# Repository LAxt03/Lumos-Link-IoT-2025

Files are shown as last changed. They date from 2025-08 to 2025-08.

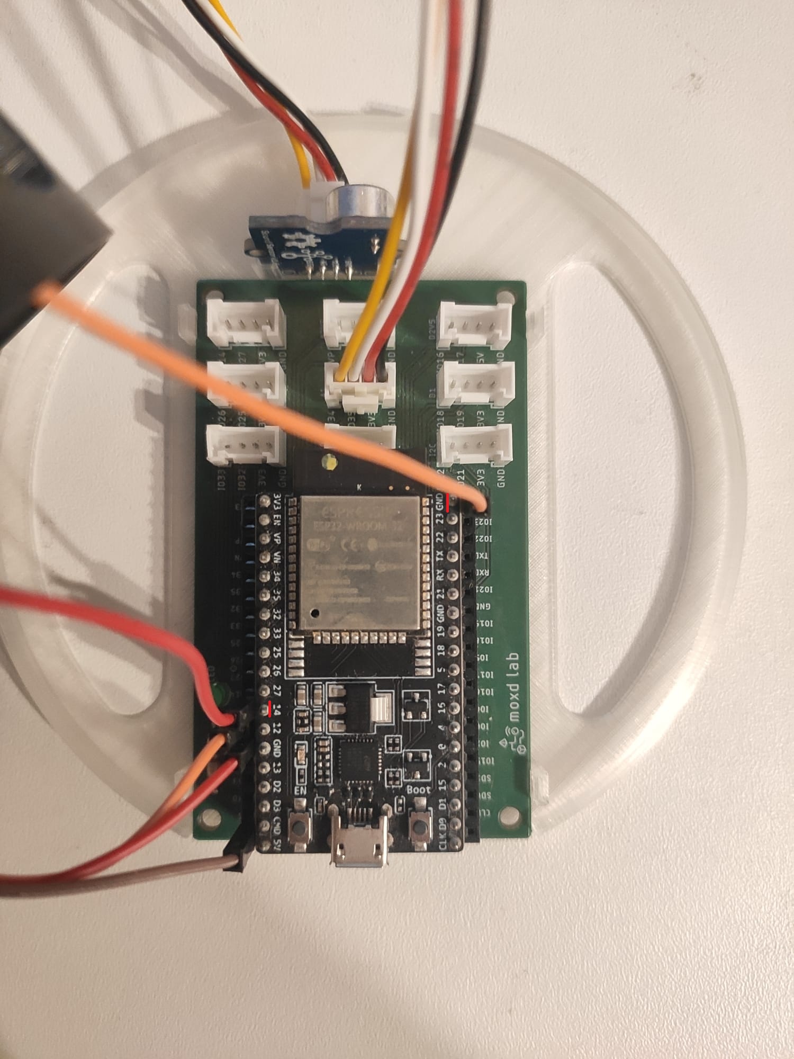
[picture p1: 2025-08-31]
DIY - Bilder/Schritt 11 -- Äußerer Taster an ESP32 anschließen.jpeg

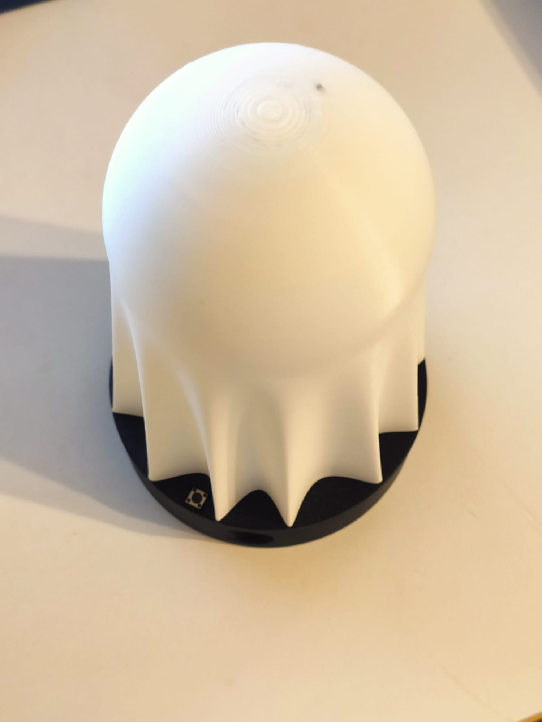
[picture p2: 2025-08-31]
DIY - Bilder/Schritt 17 -- Lumos-Geist über den Stabilitätsring platzieren.jpeg

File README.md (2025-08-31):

# Lumos-Link-IoT-2025
# DIY-Anleitung: Lumos-Lampe

Diese Anleitung beschreibt Schritt für Schritt, wie du deine Lumos-Lampe mit ESP32 und Sensoren aufbaust.
Zu allen Schritten der Aufbauanleitung sind Bilder in dem Ordner "DIY - Bilder" hinterlegt.

---

## 🔧 Benötigte Teile

- **1x ESP32**
- **1x LED-Ring**
- **1x Lichtsensor**
- **1x Sound-Sensor**
- **2x Taster** (jeweils mit 2 Kabeln angeschlossen)
- **1x 3-poliges Kabel**
- **3x Jumperkabel**
- **1x Plastikbase** (schwarz oder weiß)
- **1x transparente Plastikplatte**
- **1x LED-Ring-Kappe**
- **1x Lumos-Geist**
- **1x Stabilitätsring**

---

## 📖 Erklärung der Teile

- **ESP32**  
  Zentrale Steuereinheit, übernimmt die gesamte Logik, WLAN-Verbindung und Kommunikation über MQTT.  

- **LED-Ring**  
  Dient als visuelles Ausgabeelement und zeigt unterschiedliche Lichtmuster und Farben abhängig vom Zustand des Systems.  

- **Lichtsensor**  
  Misst die Umgebungshelligkeit, damit die Lampe nicht zu hell leuchtet und sich an die Lichtverhältnisse anpasst.  

- **Sound-Sensor**  
  Erkennt Geräusche in der Umgebung und dient als Auslöser für die Signale, die an andere Lumos-Lampen gesendet werden.  

- **2x Taster**  
  - **Aus-Taster**: Schaltet die Lampe aus.  
  - **Reset-Taster**: Startet das WiFiManager-Portal zur Neukonfiguration.  

- **3-poliges Kabel**  
  Verbindet den LED-Ring mit dem ESP32 (GND, Power, Data).  

- **3x Jumperkabel**  
  Dienen der flexiblen Verbindung von Sensoren mit den entsprechenden GPIO-Pins des ESP32.  

- **Plastikbase**  
  Fundament und Halterung für die gesamte Konstruktion, sorgt für Stabilität.  

- **Transparente Plastikplatte**  
  Trägerplatte für den ESP32 und andere elektronische Komponenten.  

- **LED-Ring-Kappe**  
  Schützt den LED-Ring und sorgt für eine gleichmäßige Lichtstreuung.  

- **Lumos-Geist**  
  Dekorative Abdeckung in Geisterform, die dem Projekt seinen charakteristischen Look gibt.  

- **Stabilitätsring**  
  Fixiert den Lumos-Geist auf der Base und sorgt für einen sicheren Halt.  

---

## 🛠️ Aufbauanleitung

### Schritt 1 – Vorbereitung
1. Den **ESP32** in die transparente Plastikplatte einklinken.  
   → Achte darauf, dass der Stromanschluss zur Kante der Platte zeigt.  
2. Den **Sound-Sensor** direkt neben dem ESP32 einklinken.  

---

### Schritt 2 – LED-Ring einsetzen
3. Den **LED-Ring** von oben mittig auf die Plastikbase legen, Pins nach unten.  
4. Die **LED-Ring-Kappe** darüber platzieren und mit der Base einrasten.  

---

### Schritt 3 – Taster montieren
5. Die beiden **Taster** von oben in die Plastikbase einsetzen.  
   → Kabel von oben durchstecken und die Taster einrasten lassen.  

---

### Schritt 4 – Sensoren einsetzen
6. Den **Lichtsensor** mit dem Anschluss nach unten in die Base, direkt neben dem LED-Ring stecken.  
7. **Jumperkabel** am Lichtsensor anschließen.  
8. **Jumperkabel** am Sound-Sensor anschließen.  

---

### Schritt 5 – Elektrische Verkabelung
9. Das **3-Pol-Kabel** am LED-Ring anschließen:  
   - GND → GND  
   - Power → 5V  
   - Data Input → Pin 12  

10. Anschlüsse LED-Ring zum ESP32:  
    - GND → GND  
    - Power → 5V  
    - Data → GPIO 12  

11. Äußerer Taster (Rand der Base):  
    - ein Kabel → GND  
    - ein Kabel → GPIO 14  

12. Innerer Taster (neben Lichtsensor):  
    - ein Kabel → GND  
    - ein Kabel → GPIO 4  

13. Sound-Sensor:  
    - Jumperkabel → GPIO 34  

14. Lichtsensor:  
    - Jumperkabel → GPIO 33  

---

### Schritt 6 – Zusammenbau
15. Die **Plastikbase** auf die transparente Plastikplatte stecken.  
    → Kabel ordentlich verstauen, damit kein Anschluss blockiert wird.  
16. Den **Stabilitätsring** auf die Plastikbase setzen.  
17. Den **Lumos-Geist** über den Stabilitätsring platzieren.  

---

Fertig! Deine Lumos-Lampe ist nun aufgebaut und bereit zur Inbetriebnahme.

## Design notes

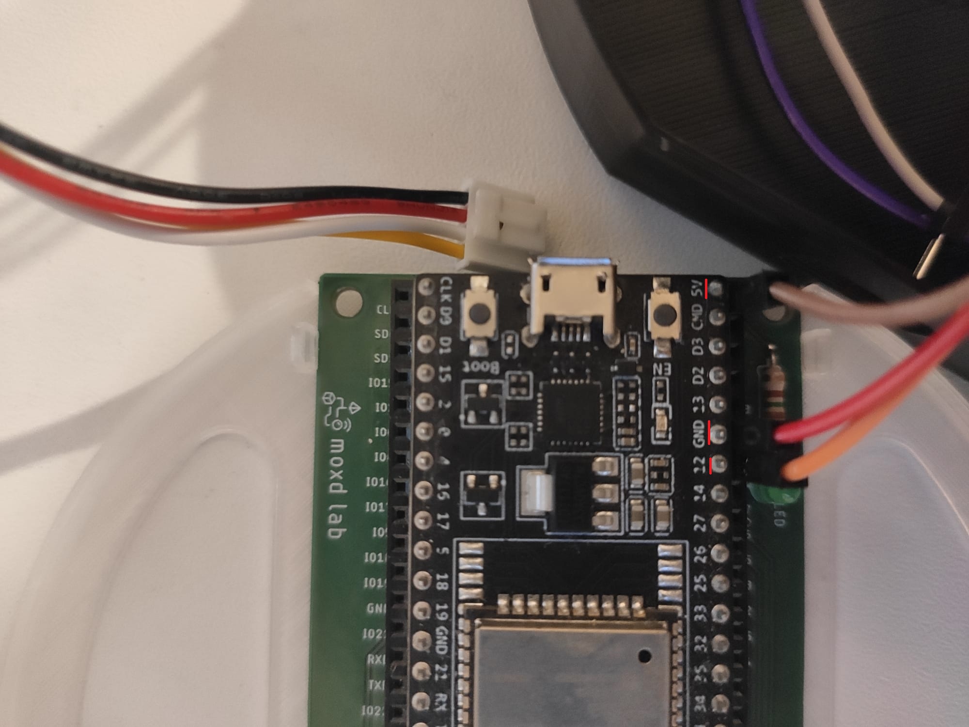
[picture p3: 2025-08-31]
DIY - Bilder/Schritt 10 -- Anschlüsse LED-Ring zum ESP32.jpeg

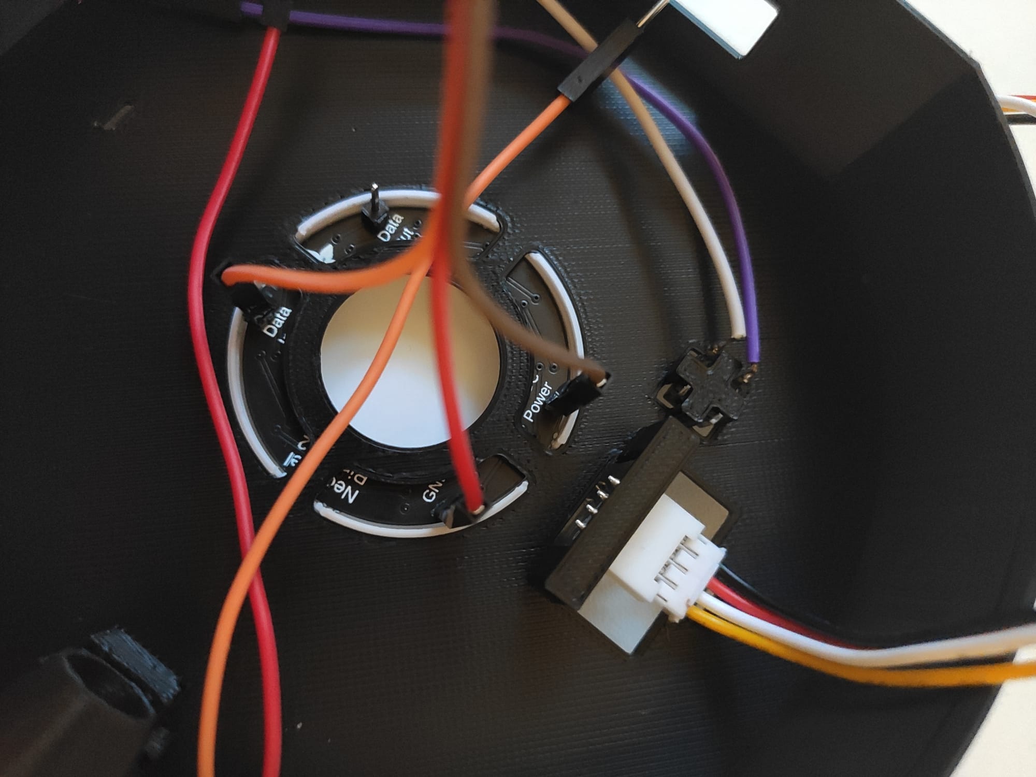
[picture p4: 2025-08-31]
DIY - Bilder/Schritt 9 -- 3-Pol-Kabel am LED-Ring anschließen.jpeg

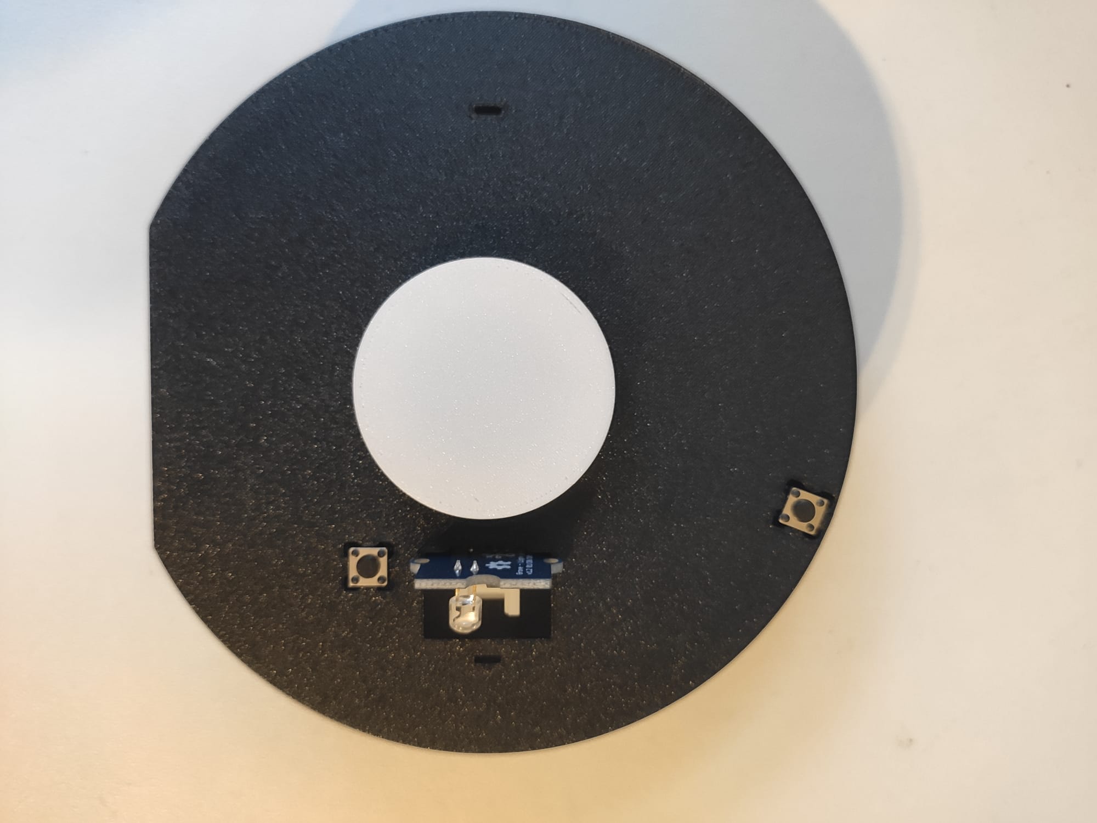
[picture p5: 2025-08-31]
DIY - Bilder/Schritt 6 -- Lichtsensor einsetzten.jpeg

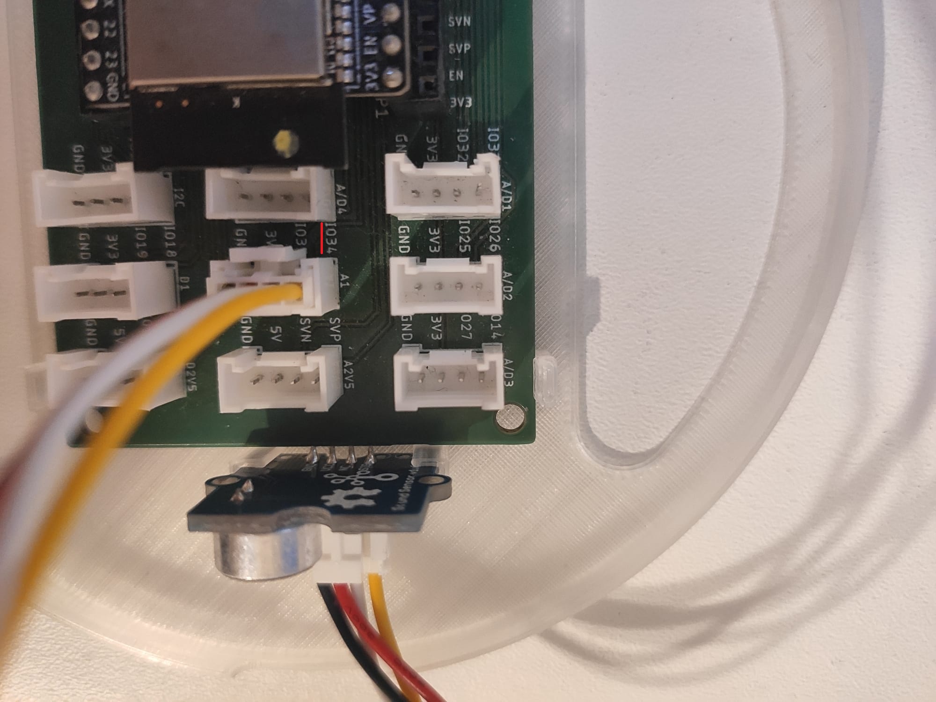
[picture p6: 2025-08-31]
DIY - Bilder/Schritt 13 -- Sound-Sensor Jumperkabel an GPIO 34 anschließen.jpeg

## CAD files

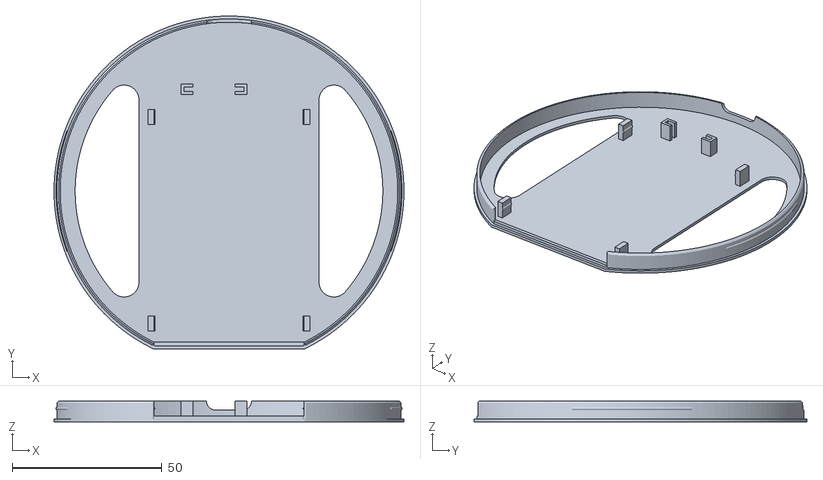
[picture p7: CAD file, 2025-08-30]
Lumos stl/Lumos-lower-case.stl
117.1 x 111.4 x 7.00

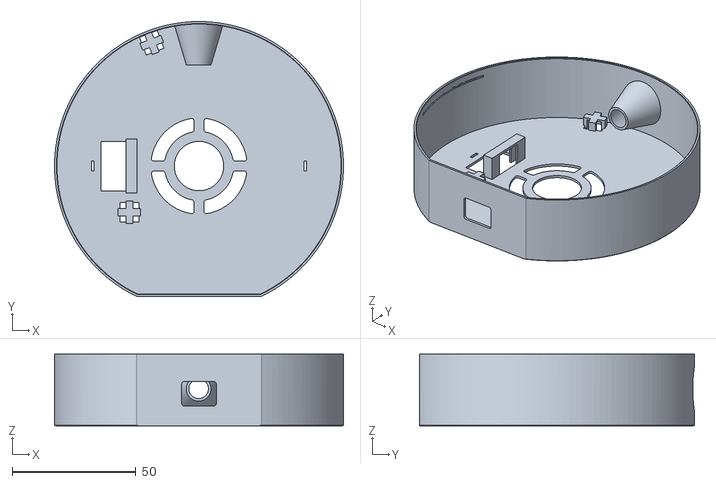
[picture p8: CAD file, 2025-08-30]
Lumos stl/Lumos-upper-case.stl
117.0 x 111.3 x 29.0

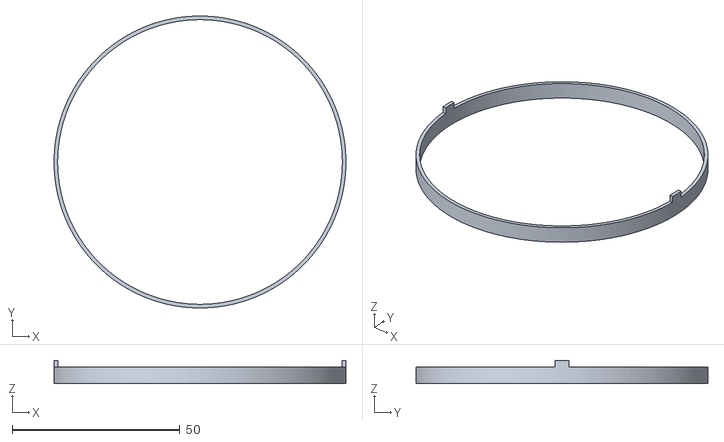
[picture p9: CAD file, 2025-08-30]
Lumos stl/Lumos-positioner-ring.stl
87.1 x 87.1 x 7.00

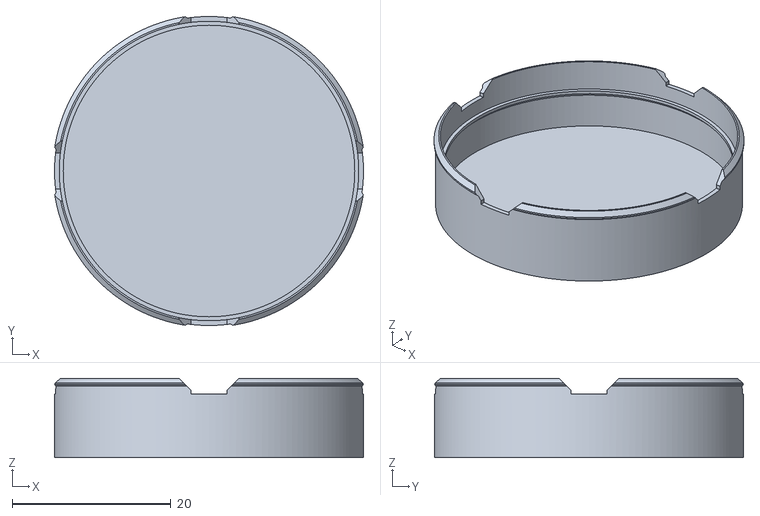
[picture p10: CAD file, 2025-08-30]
Lumos stl/Lumos-light-defuser.stl
38.9 x 38.9 x 10.0

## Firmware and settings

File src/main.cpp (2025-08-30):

#include <Arduino.h>
#include <PubSubClient.h>
#include <ArduinoJson.h>
#include <WiFiManager.h> // Für WLAN-Konfiguration
#include <Preferences.h> // Für dauerhafte Speicherung
#include <Adafruit_NeoPixel.h>
Preferences prefs;
// === Pins ===
const int lightSensPin = 33;
const int soundPin = 34;
const int ledPin = 12;
const int turn_off_button = 14; // muss ein pin mit PULL-UP-RESISTOR sein
const int reset_button =4;     // muss ein pin mit PULL-UP-RESISTOR sein

// === LED DATA ===
const int NUMPIXELS = 12;
Adafruit_NeoPixel pixels = Adafruit_NeoPixel(NUMPIXELS, ledPin, NEO_GRB + NEO_KHZ800);
unsigned int RGB_values[3] = {0, 0, 0};


// Wifi Manager Parameter
char mqtt_broker[40];
char mqtt_port[6];
char mqtt_username[32];
char mqtt_password[32];
unsigned long lamp1 = 0;
unsigned long lamp2 = 0;
unsigned long lamp3 = 0;

// === Luminos Connection Data ===
const int partners_count = 3;
unsigned long partners[partners_count]; // IDs der anderen lumose die Durch Wifimaneger gestellt werden

const unsigned long lumos_id = 0x00000001; // MAX:0xFFFFFFFF

// WiFiManager
WiFiManager wm;

WiFiClient espClient;
PubSubClient client(espClient);

void saveConfig()
{
    prefs.begin("mqtt", false);
    prefs.putString("broker", mqtt_broker);
    prefs.putString("port", mqtt_port);
    prefs.putString("lamp1", String(lamp1, HEX));
    prefs.putString("lamp2", String(lamp2, HEX));
    prefs.putString("lamp3", String(lamp3, HEX));
    prefs.putString("mqtt username", mqtt_username);
    prefs.putString("mqtt password", mqtt_password);
    prefs.end();
    Serial.println("[INFO] Konfiguration gespeichert");
}

// Lädt die Configuration aus dem NVS Speicher
void loadConfig()
{
    prefs.begin("mqtt", true);
    String b = prefs.getString("broker", "");
    String p = prefs.getString("port", "");
    String u = prefs.getString("mqtt username", "");
    String pw = prefs.getString("mqtt password", "");

    lamp1 = strtoul(prefs.getString("lamp1", "0").c_str(), NULL, 16);
    lamp2 = strtoul(prefs.getString("lamp2", "0").c_str(), NULL, 16);
    lamp3 = strtoul(prefs.getString("lamp3", "0").c_str(), NULL, 16);

    partners[0] = lamp1;
    partners[1] = lamp2;
    partners[2] = lamp3;

    prefs.end();

    b.toCharArray(mqtt_broker, sizeof(mqtt_broker));
    p.toCharArray(mqtt_port, sizeof(mqtt_port));
    u.toCharArray(mqtt_username, sizeof(mqtt_username));
    pw.toCharArray(mqtt_password, sizeof(mqtt_password));

    Serial.println("[INFO] Geladene Konfiguration:");
    Serial.printf("MQTT Broker: %s\n", mqtt_broker);
    Serial.printf("MQTT Port: %s\n", mqtt_port);
    Serial.printf("Lampe1: %08lX\n", lamp1);
    Serial.printf("Lampe2: %08lX\n", lamp2);
    Serial.printf("Lampe3: %08lX\n", lamp3);
    Serial.printf("MQTT Username: %s\n", mqtt_username);
    // Serial.printf("MQTT Password: %s\n", mqtt_password); // Passwort nicht ausgeben
}

// Config Portal starten
void startConfigPortal()
{
    //Animation Start
    Serial.println("[INFO] Starte Konfigurations-Portal...");

    // Custom Parameter anlegen
    WiFiManagerParameter custom_mqtt_broker("broker", "MQTT Broker IP", mqtt_broker, 40);
    WiFiManagerParameter custom_mqtt_port("port", "MQTT Port", mqtt_port, 6);
    WiFiManagerParameter custom_mqtt_username("username", "MQTT Username", mqtt_username, 32);
    WiFiManagerParameter custom_mqtt_password("password", "MQTT Password", mqtt_password, 32);
    WiFiManagerParameter custom_lamp1("lamp1", "Lampe 1 ID (HEX)", "", 32);
    WiFiManagerParameter custom_lamp2("lamp2", "Lampe 2 ID (HEX)", "", 32);
    WiFiManagerParameter custom_lamp3("lamp3", "Lampe 3 ID (HEX)", "", 32);

    wm.addParameter(&custom_mqtt_broker);
    wm.addParameter(&custom_mqtt_port);
    wm.addParameter(&custom_mqtt_username);
    wm.addParameter(&custom_mqtt_password);
    wm.addParameter(&custom_lamp1);
    wm.addParameter(&custom_lamp2);
    wm.addParameter(&custom_lamp3);

    wm.setConfigPortalTimeout(300); // 5 Minuten

    if (!wm.startConfigPortal("Lumos-Lampe"))
    {
        Serial.println("[WARN] Konnte kein WLAN verbinden, Neustart...");
        delay(3000);
        ESP.restart();
    }

    // Werte auslesen und speichern
    strcpy(mqtt_broker, custom_mqtt_broker.getValue());
    strcpy(mqtt_port, custom_mqtt_port.getValue());
    strcpy(mqtt_username, custom_mqtt_username.getValue());
    strcpy(mqtt_password, custom_mqtt_password.getValue());

    lamp1 = strtoul(custom_lamp1.getValue(), NULL, 16);
    lamp2 = strtoul(custom_lamp2.getValue(), NULL, 16);
    lamp3 = strtoul(custom_lamp3.getValue(), NULL, 16);

    partners[0] = lamp1;
    partners[1] = lamp2;
    partners[2] = lamp3;

    saveConfig();

    Serial.println("[INFO] WLAN und MQTT Parameter gespeichert");
}

// === MQTT ===
void callback(char *topic, byte *payload, unsigned int length)
{ // function die aufgerufen wird wenn auf den gefolgten MQTT kanal was gesendet wurde
    String message = String();
    for (int i = 0; i < length; i++)
    {
        message.concat((char)payload[i]);
    }
    // Serial.println(message);
    analogWrite(ledPin, message.toInt());
    // Serial.println("-----------------------");
    for (int i = 0; i < partners_count; i++)
    { // TODO: Was wenn ein lumos nicht mehr sendet und der letzte wert nicht 0 war?
        if (strcmp(String(partners[i], HEX).c_str(), topic) == 0)
        {
            int value = message.toInt();
            if (value > 255)
            {
                RGB_values[i] = 255;
            }
            else
            {
                RGB_values[i] = value;
            }
        }
    }
}


void reset_button_loop();

void build_MQTT_connection()
{
    client.setServer(mqtt_broker, atoi(mqtt_port));
    client.setCallback(callback);
    while (!client.connected())
    {
        reset_button_loop();
        String client_id = String(lumos_id, HEX);
        Serial.printf("The client %s connects to the public MQTT broker\n", client_id.c_str());
        if (client.connect(client_id.c_str(), mqtt_username, mqtt_password))
        {
            Serial.println("Public EMQX MQTT broker connected");
        }
        else
        {
            Serial.print("failed with state ");
            Serial.print(client.state());
            delay(2000);
        }
    }
}
void sub_to_lumos()
{
    for (int i = 0; i < partners_count; i++)
    {
        if (partners[i] != 0)
        {
            client.subscribe(String(partners[i], HEX).c_str());
            Serial.print("Subscrinbed to: ");
            Serial.println(String(partners[i], HEX).c_str());
        }
    }
}

// === Sound handling ===
int last_last_sound = 0;
int last_sound = 0;
int measureSound()
{
    int reading = analogRead(soundPin);
    if (reading < 0)
    {
        reading = -reading;
    }
    reading = (reading / 4);
    if (reading < 27)
    {
        reading = 0;
    }
    reading = (reading + 3 * last_sound) / 4;
    reading = (reading + last_last_sound) / 2;
    if (reading < 15)
    {
        reading = reading / 4;
    }
    last_last_sound = last_sound;
    last_sound = reading;
    return reading;
}

// === LED functions ===
void draw_led(int R, int G, int B)
{
    for (int i = 0; i < NUMPIXELS; i++)
    {
        pixels.setPixelColor(i, pixels.Color(R, G, B));
    }
    pixels.show();
}

void draw_led(int R, int G, int B, int Brightness)
{
    for (int i = 0; i < NUMPIXELS; i++)
    {
        pixels.setPixelColor(i, pixels.Color(
                                    static_cast<int>(static_cast<float>(R) * static_cast<float>(Brightness) / 100), // für Prozentrechnungen werden die Integer zu Floats gecastet und wieder zurück
                                    static_cast<int>(static_cast<float>(G) * static_cast<float>(Brightness) / 100),
                                    static_cast<int>(static_cast<float>(B) * static_cast<float>(Brightness) / 100)));
    }
    pixels.show();
}

void loading_animation(int R, int G, int B)
{
    while (true)
    {
        for (int i = 0; i < NUMPIXELS; i++)
        {
            pixels.setPixelColor(i, pixels.Color(R, G, B));
            pixels.show();
            pixels.setPixelColor(i, pixels.Color(0, 0, 0));
            delay(50);
        }
    }
}
void loading_animation_MQTT(void *pvParameters)
{
    loading_animation(255, 0, 255);
}
void loading_animation_WIFI(void *pvParameters)
{
    loading_animation(0, 255, 255);
}

TaskHandle_t Wifi_loading;
TaskHandle_t MQTT_loading;

// xTaskCreatePinnedToCore(loading_animation_MQTT,"MQTT_loading",10000,NULL,1,&Wifi_loading,0);

// === Button action ===

void off_button_loop()
{ //
    if (digitalRead(turn_off_button) == LOW)
    {
        Serial.println("off Button pressed");
        for (int i = 0; i < 3; i++)
        {
            client.publish(String(lumos_id, HEX).c_str(), std::to_string(3).c_str());
            delay(50);
        }
        draw_led(0, 0, 0);
        delay(50);
        esp_deep_sleep_start(); // Geht in den DEEP_SLEEP wo nur noch der co-Prozessor aktiv ist.
    }
}

// === Reset Button ===
void reset_button_loop()
{

    if (digitalRead(reset_button) == LOW)
    {
        Serial.println("RESET Button pressed");
            startConfigPortal();
    }
}

// === Adaptive brightness ===
int loops_sins_brightness_measured = 0;
int led_brightness = 100;
void adapt_brightness()
{
    if (RGB_values[0] + RGB_values[1] + RGB_values[2] == 0 || loops_sins_brightness_measured > 500)
    {
        draw_led(0, 0, 0);
        int brightness = analogRead(lightSensPin);
        draw_led(RGB_values[0], RGB_values[1], RGB_values[2], led_brightness);
        if (brightness > 1500)
        {
            led_brightness = 100;
        }
        else if (brightness > 500)
        {
            led_brightness = 60;
        }
        else if (brightness > 200)
        {
            led_brightness = 10;
        }
        loops_sins_brightness_measured = 0;
    }
    loops_sins_brightness_measured++;
}

void setup()
{
    Serial.begin(115200);
    pinMode(ledPin, OUTPUT);
    pinMode(turn_off_button, INPUT_PULLUP);
    pinMode(reset_button, INPUT_PULLUP);

    // Lade gespeicherte MQTT-Konfig
    loadConfig();

    // WLAN verbinden oder Portal starten
    if (!wm.autoConnect("Lumos-Lampe"))
    {
        Serial.println("[WARN] Keine Verbindung -> Neustart");
        delay(3000);
        ESP.restart();
    }
    Serial.println("[INFO] Mit WLAN verbunden");

    esp_sleep_enable_ext0_wakeup(GPIO_NUM_14, LOW);
    xTaskCreate(loading_animation_WIFI, "Wifi_loading", 10000, NULL, 1, &Wifi_loading); // Animation fürs laden die nebenläufig ist
    vTaskDelete(Wifi_loading);
    xTaskCreate(loading_animation_MQTT, "MQTT_loading", 10000, NULL, 1, &MQTT_loading); // Animation fürs laden die nebenläufig ist
    build_MQTT_connection();
    sub_to_lumos();
    vTaskDelete(MQTT_loading);
}

void loop()
{
    if (WiFi.status() != WL_CONNECTED){
        Serial.println("WiFi reconnecting");
        xTaskCreate(loading_animation_WIFI, "Wifi_loading", 10000, NULL, 1, &Wifi_loading);
        WiFi.reconnect();
        vTaskDelete(Wifi_loading);
        Serial.println("WiFi reconnected");
    }
    else if (!client.loop()){
        Serial.println("MQTT Client reconnecting");
        xTaskCreate(loading_animation_MQTT, "MQTT_loading", 10000, NULL, 1, &MQTT_loading);
        build_MQTT_connection();
        sub_to_lumos();
        vTaskDelete(MQTT_loading);
        Serial.println("MQTT Client reconnected");
    }
    client.loop();
    client.publish(String(lumos_id, HEX).c_str(), std::to_string(measureSound()).c_str());
    adapt_brightness();
    draw_led(RGB_values[0], RGB_values[1], RGB_values[2], led_brightness);
    off_button_loop();
    reset_button_loop(); // Prüft ob der Reset Button gedrückt wurde
}

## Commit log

2025-08-30 Added neopixle led ring and rgb logic for multiple connections
2025-08-30 off Button added
2025-08-30 Added WiFi Maneger (Bugged animations)
    [main.cpp]
2025-08-30 Added STL files
    [Lumos-light-defuser.stl, Lumos-lower-case.stl, Lumos-positioner-ring.stl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]
2025-08-31 Update README.md
    Erklärung der Teile hinzugefügt und Verweis zu den DIY - Bildern
2025-08-31 Create "DIY - Bilder" Ordner
    Ordner für die "DIY - Bilder"
2025-08-31 Rename WhatsApp Image 2025-08-31 at 20.37.26.jpeg to Schritt 1 - ESP32 einklinken.jpeg
2025-08-31 Rename Schritt 1 - ESP32 einklinken.jpeg to Schritt 1 - ESP32 einklinken
2025-08-31 Rename Schritt 1 - ESP32 einklinken to Schritt 1 - ESP32 einklinken.jpeg
2025-08-31 Rename WhatsApp Image 2025-08-31 at 20.37.26(1).jpeg to Schritt 1 - ESP32 einklinken.jpeg
2025-08-31 Rename WhatsApp Image 2025-08-31 at 20.37.26(2).jpeg to Schritt 2 -- Sound-Sensor einklinken
2025-08-31 Rename Schritt 2 -- Sound-Sensor einklinken to Schritt 2 -- Sound-Sensor einklinken.jpeg
2025-08-31 Rename WhatsApp Image 2025-08-31 at 20.37.26(3).jpeg to Schritt 3 -- LED-Ring einsetzen.jpeg
2025-08-31 Rename WhatsApp Image 2025-08-31 at 20.37.26(4).jpeg to Schritt 4 -- LED-Ring-Kappe einklinken.jpeg
2025-08-31 Rename WhatsApp Image 2025-08-31 at 20.37.26(9).jpeg to Schritt 8 -- Jumperkabel an Sound-Sensor anschließen.jpeg
2025-08-31 Rename WhatsApp Image 2025-08-31 at 20.37.26(10).jpeg to Schritt 9 -- 3-Pol-Kabel am LED-Ring anschließen.jpeg
2025-08-31 Rename WhatsApp Image 2025-08-31 at 20.37.26(12).jpeg to Schritt 10 -- Anschlüsse LED-Ring zum ESP32.jpeg
2025-08-31 Rename WhatsApp Image 2025-08-31 at 20.37.26(13).jpeg to Schritt 11 -- Äußerer Taster an ESP32 anschließen.jpeg
2025-08-31 Rename WhatsApp Image 2025-08-31 at 20.37.26(14).jpeg to Schritt 12 -- Innerer Taster an ESP32 anschließen.jpeg
2025-08-31 Rename WhatsApp Image 2025-08-31 at 20.37.26(11).jpeg to Schritt 13 -- Sound-Sensor Jumperkabel an GPIO 34 anschließen.jpeg
